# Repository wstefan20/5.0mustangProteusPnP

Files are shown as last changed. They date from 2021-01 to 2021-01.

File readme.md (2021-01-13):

# 5.0 Mustang Proteus PnP
PnP adapter board for 5.0 mustang EEC-IV computer using Proteus Rusefi v0.5 compatible board.

This board is designed as both a PnP stock replacement for the A9L/A9P EECs found in 5.0 manual foxbody mustangs, as well as a fully featured aftermarket ECU. This board is designed to fit into BOTH versions of the stock Ford EEC-IV case.

PLEASE do not rip apart any A9L computers to house this unit, there's very few of them left and they sell for a lot! Keep or sell that and buy any late 80s to early 90s EEC-IV as a donor instead such as 88 ford taurus 2.4 EEC for $25.

wiki and more info coming after fully tested.

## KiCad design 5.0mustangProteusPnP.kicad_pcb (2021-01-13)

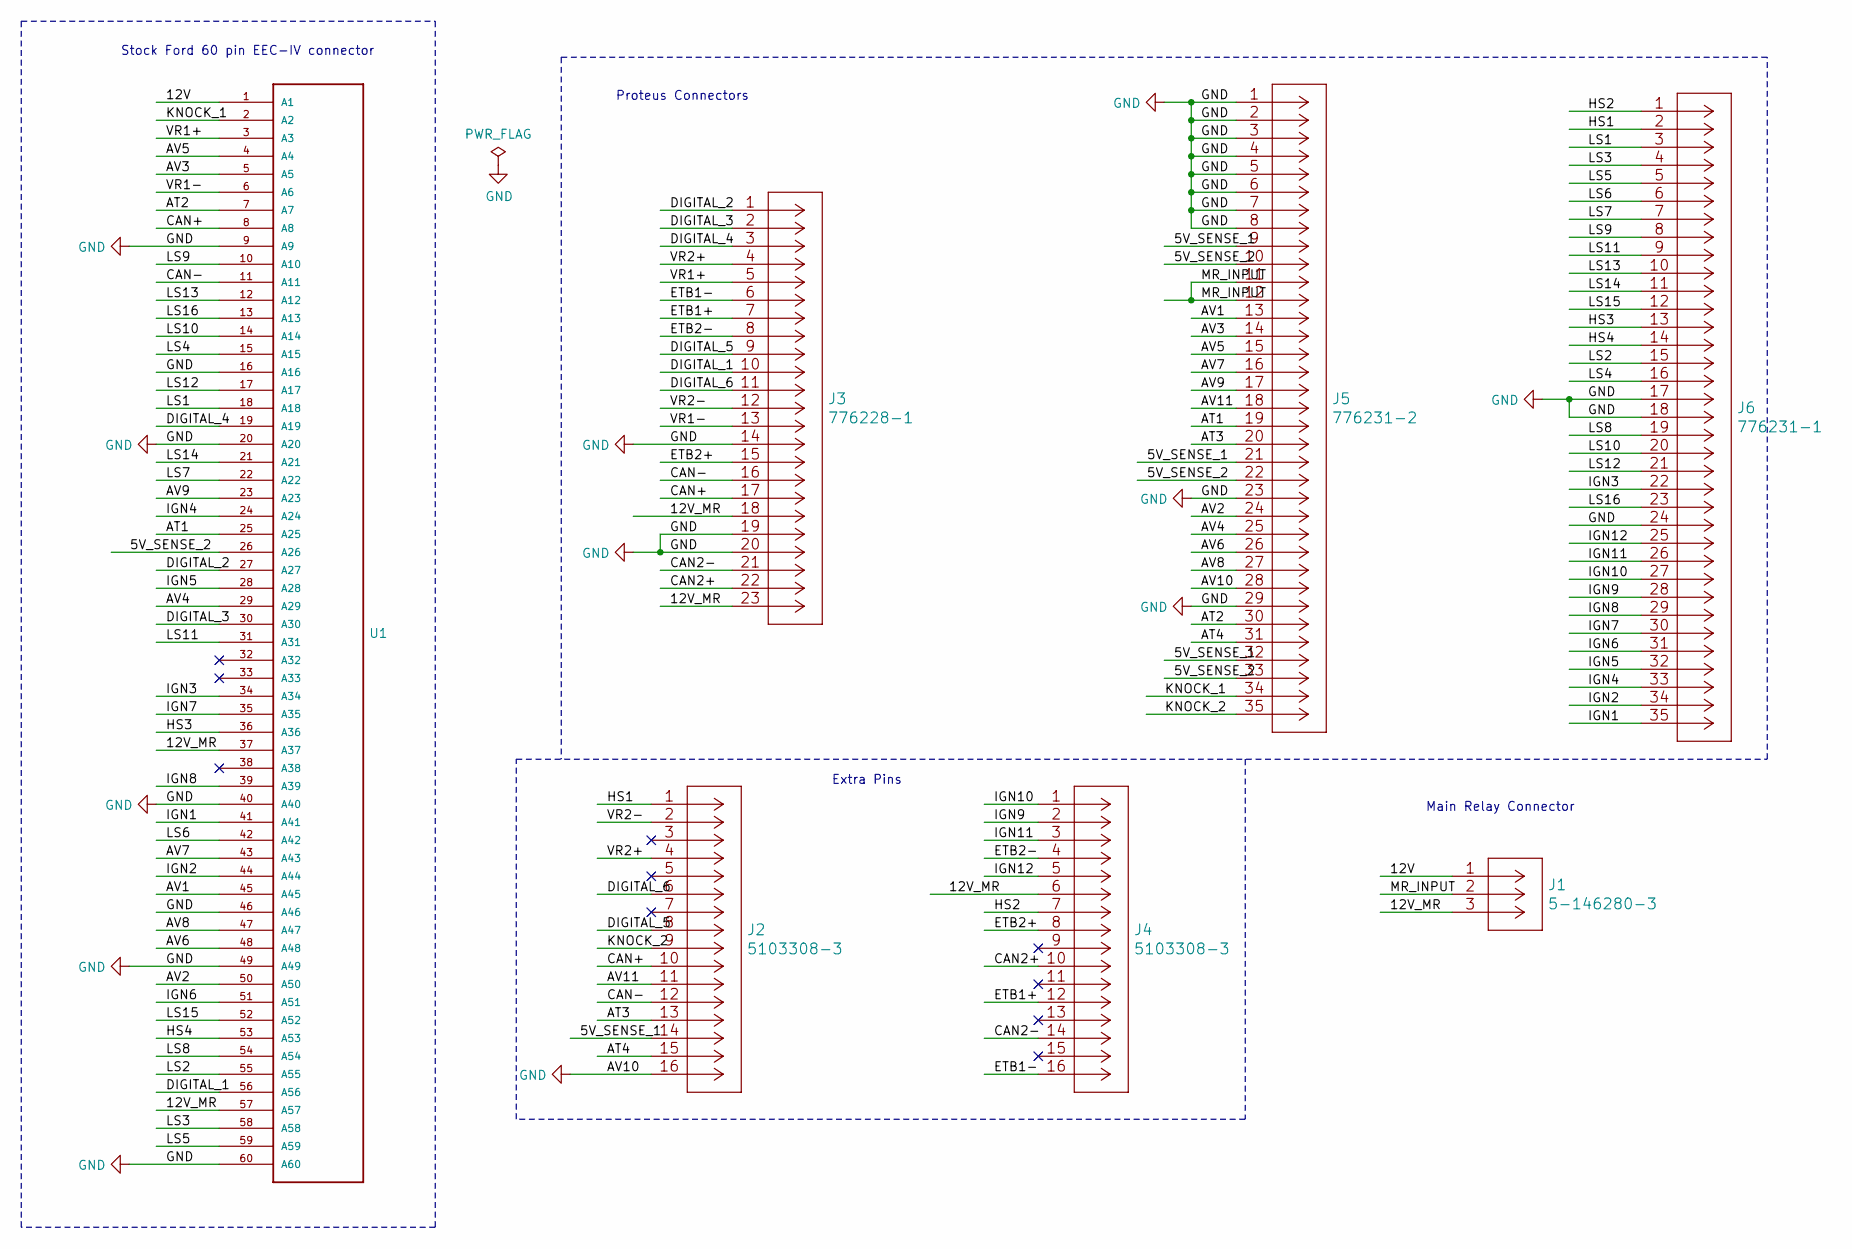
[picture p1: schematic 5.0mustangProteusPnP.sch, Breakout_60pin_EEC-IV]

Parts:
J1: 5-146280-3
J2, J4: 5103308-3
J3: 776228-1
J5: 776231-2
J6: 776231-1
U1: FORD60PIN

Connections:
/5V_SENSE_1: J2.14, J5.9, J5.21, J5.32
/5V_SENSE_2: J5.10, J5.22, J5.33, U1.26 (A26)
/12V: J1.1, U1.1 (A1)
/12V_MR: J1.3, J3.18, J3.23, J4.6, U1.37 (A37), U1.57 (A57)
/AT1: J5.19, U1.25 (A25)
/AT2: J5.30, U1.7 (A7)
/AT3: J2.13, J5.20
/AT4: J2.15, J5.31
/AV1: J5.13, U1.45 (A45)
/AV2: J5.24, U1.50 (A50)
/AV3: J5.14, U1.5 (A5)
/AV4: J5.25, U1.29 (A29)
/AV5: J5.15, U1.4 (A4)
/AV6: J5.26, U1.48 (A48)
/AV7: J5.16, U1.43 (A43)
/AV8: J5.27, U1.47 (A47)
/AV9: J5.17, U1.23 (A23)
/AV11: J2.11, J5.18
/CAN2+: J3.22, J4.10
/CAN2-: J3.21, J4.14
/CAN+: J2.10, J3.17, U1.8 (A8)
/CAN-: J2.12, J3.16, U1.11 (A11)
/DIGITAL_1: J3.10, U1.56 (A56)
/DIGITAL_2: J3.1, U1.27 (A27)
/DIGITAL_3: J3.2, U1.30 (A30)
/DIGITAL_4: J3.3, U1.19 (A19)
/DIGITAL_5: J2.8, J3.9
/DIGITAL_6: J2.6, J3.11
/ETB1+: J3.7, J4.12
/ETB1-: J3.6, J4.16
/ETB2+: J3.15, J4.8
/ETB2-: J3.8, J4.4
/HS1: J2.1, J6.2
/HS2: J4.7, J6.1
/HS3: J6.13, U1.36 (A36)
/HS4: J6.14, U1.53 (A53)
/IGN1: J6.35, U1.41 (A41)
/IGN2: J6.34, U1.44 (A44)
/IGN3: J6.22, U1.34 (A34)
/IGN4: J6.33, U1.24 (A24)
/IGN5: J6.32, U1.28 (A28)
/IGN6: J6.31, U1.51 (A51)
/IGN7: J6.30, U1.35 (A35)
/IGN8: J6.29, U1.39 (A39)
/IGN9: J4.2, J6.28
/IGN10: J4.1, J6.27
/IGN11: J4.3, J6.26
/IGN12: J4.5, J6.25
/KNOCK_1: J5.34, U1.2 (A2)
/KNOCK_2: J2.9, J5.35
/LS1: J6.3, U1.18 (A18)
/LS2: J6.15, U1.55 (A55)
/LS3: J6.4, U1.58 (A58)
/LS4: J6.16, U1.15 (A15)
/LS5: J6.5, U1.59 (A59)
/LS6: J6.6, U1.42 (A42)
/LS7: J6.7, U1.22 (A22)
/LS8: J6.19, U1.54 (A54)
/LS9: J6.8, U1.10 (A10)
/LS10: J6.20, U1.14 (A14)
/LS11: J6.9, U1.31 (A31)
/LS12: J6.21, U1.17 (A17)
/LS13: J6.10, U1.12 (A12)
/LS14: J6.11, U1.21 (A21)
/LS15: J6.12, U1.52 (A52)
/LS16: J6.23, U1.13 (A13)
/MR_INPUT: J1.2, J5.11, J5.12
/VR1+: J3.5, U1.3 (A3)
/VR1-: J3.13, U1.6 (A6)
/VR2+: J2.4, J3.4
/VR2-: J2.2, J3.12
GND: J2.16, J3.14, J3.19, J3.20, J5.1, J5.2, J5.3, J5.4, J5.5, J5.6, J5.7, J5.8, J5.23, J5.28, J5.29, J6.17, J6.18, J6.24, U1.9 (A9), U1.16 (A16), U1.20 (A20), U1.40 (A40), U1.46 (A46), U1.49 (A49), U1.60 (A60)

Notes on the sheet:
Proteus Connectors
Stock Ford 60 pin EEC-IV connector
Extra Pins
Main Relay Connector

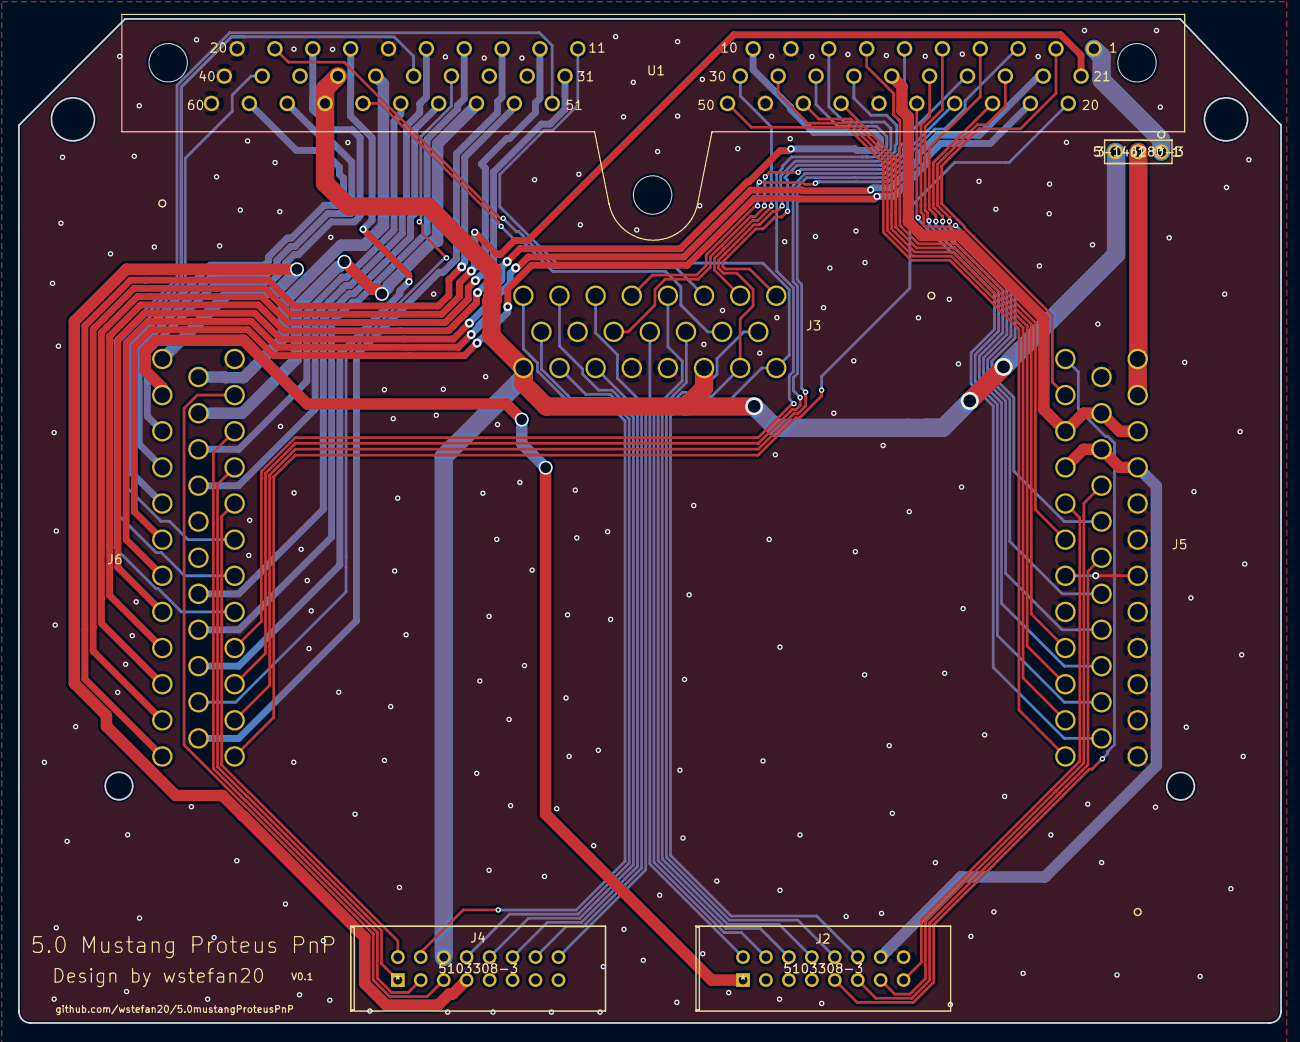
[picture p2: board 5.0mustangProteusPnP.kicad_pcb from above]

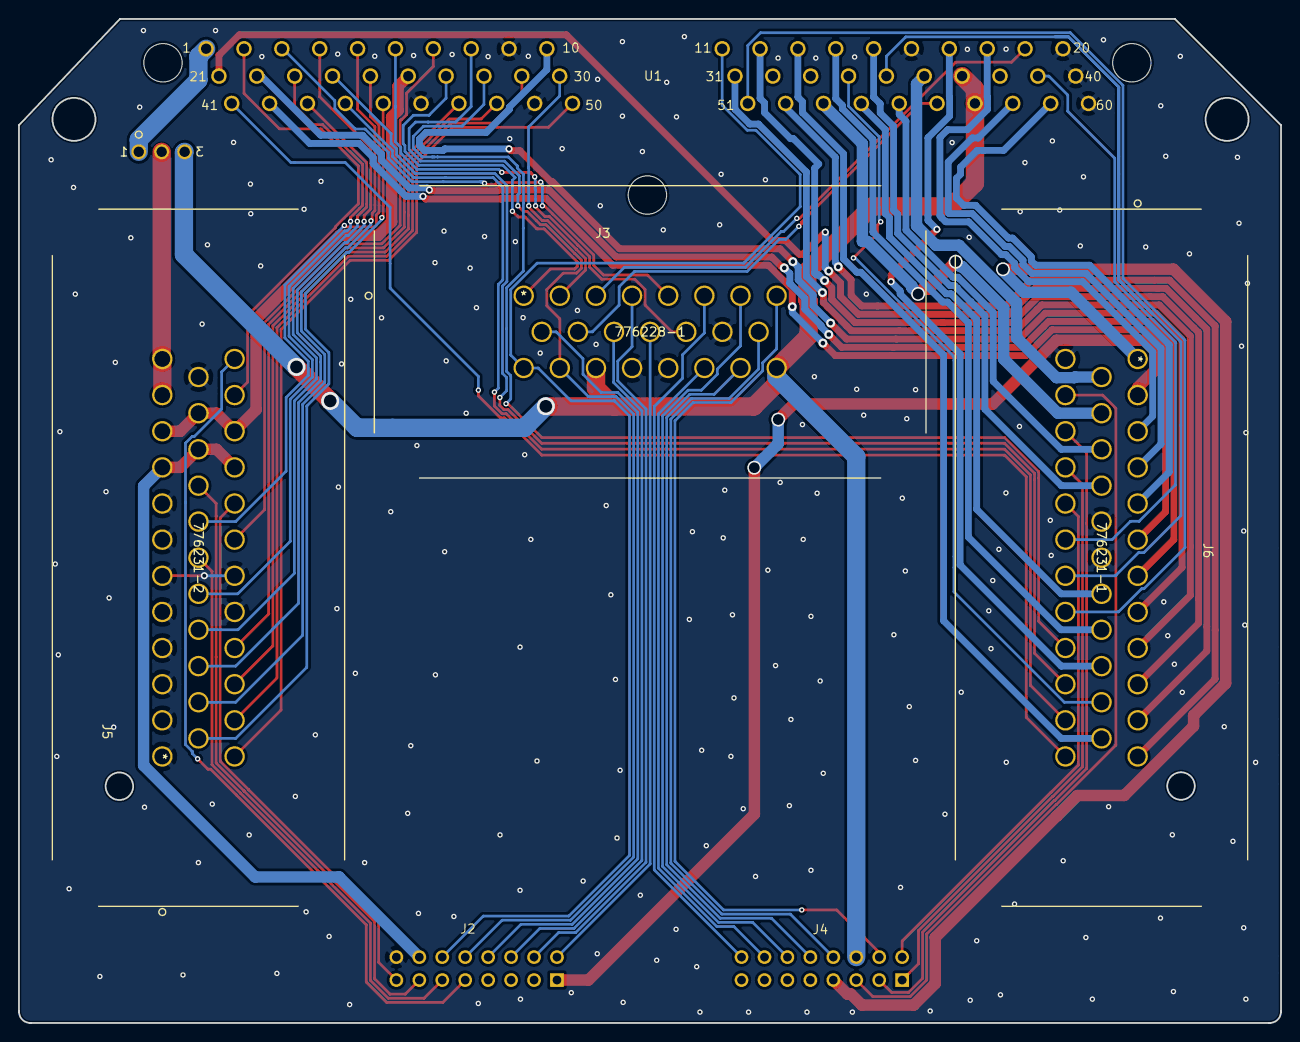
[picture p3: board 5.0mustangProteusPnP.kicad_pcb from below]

Board: 2 copper layers, 139.7 x 111.1 mm, 7 parts (3 on the bottom side), 72 nets.

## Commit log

2021-01-08 re-routed to optimise
    [5.0mustangProteusPnP-B_Cu.gbl, 5.0mustangProteusPnP-B_Mask.gbs, 5.0mustangProteusPnP-B_SilkS.gbo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]
2021-01-08 changed 12V
    [5.0mustangProteusPnP.kicad_pcb, 5.0mustangProteusPnP.sch]
2021-01-09 fixed 12V and IAC
    [5.0mustangProteusPnP.kicad_pcb, 5.0mustangProteusPnP.sch]
2021-01-09 fixed CEL assign
    [5.0mustangProteusPnP.kicad_pcb, 5.0mustangProteusPnP.sch]
2021-01-13 updated board outline/holes
    [5.0mustangProteusPnP-B_Cu.gbl, 5.0mustangProteusPnP-B_Mask.gbs, 5.0mustangProteusPnP-B_SilkS.gbo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]

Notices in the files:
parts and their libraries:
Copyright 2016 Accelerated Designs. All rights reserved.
